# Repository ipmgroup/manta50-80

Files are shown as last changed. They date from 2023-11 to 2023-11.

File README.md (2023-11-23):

# manta50-80
Motor-Controller, FOC

### Manta50 key characteristics

    DC-Input 4.4V to 45V 
    Maximum DC / AC (per phase) current - 20A
    Texas Instruments C2000 Piccolo TMS320F28027F
    CAN - MCP2515
    Three-Phase Smart Gate Driver - DRV8305
    one GPIO input for PWM(not supported in FW)

with good cooling in water, you can increase the AC current to 80A. Replacing the resistance from 0.007R to 0.002R.

#### [Firmware](https://github.com/ipmgroup/manta50_fw)

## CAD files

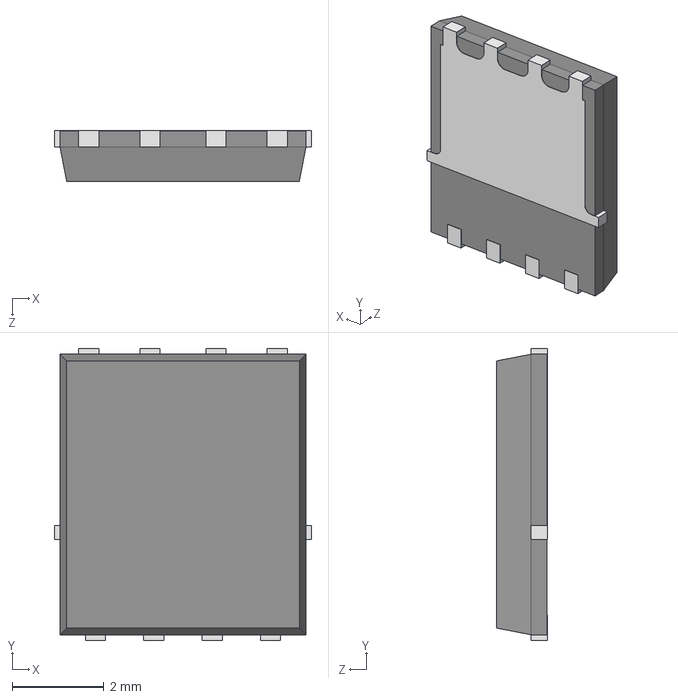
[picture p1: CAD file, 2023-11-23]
3D_MODELS/PG-TDSON-8_(INFIN).STEP
5.59 x 6.35 x 1.11 mm

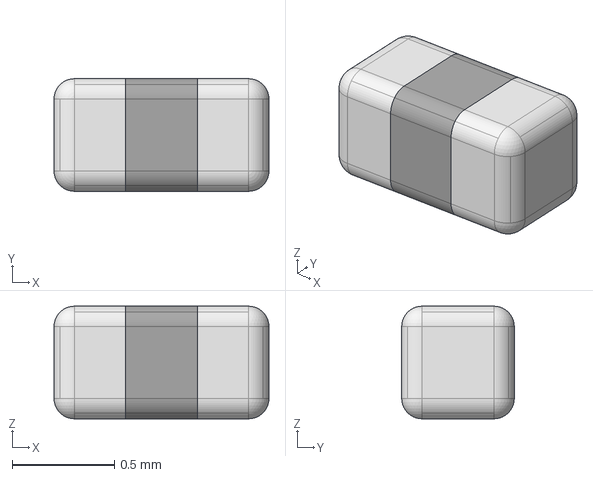
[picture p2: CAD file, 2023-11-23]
3D_MODELS/INDC1005X55N.stp
1.05 x 0.55 x 0.55 mm

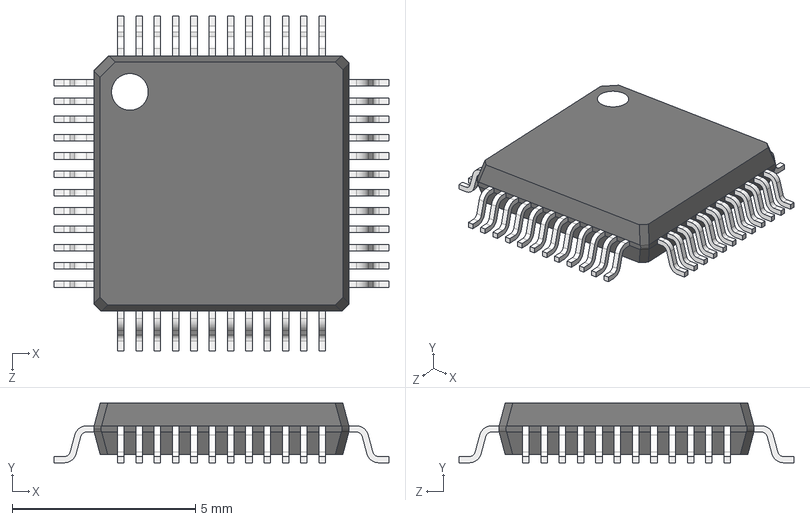
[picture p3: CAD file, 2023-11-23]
3D_MODELS/User Library-LQFP48-2.STEP
9.14 x 1.63 x 9.14 mm
User Library-LQFP48-2_case
User Library-LQFP48-2_pin x 48
User Library-LQFP48-2_circle

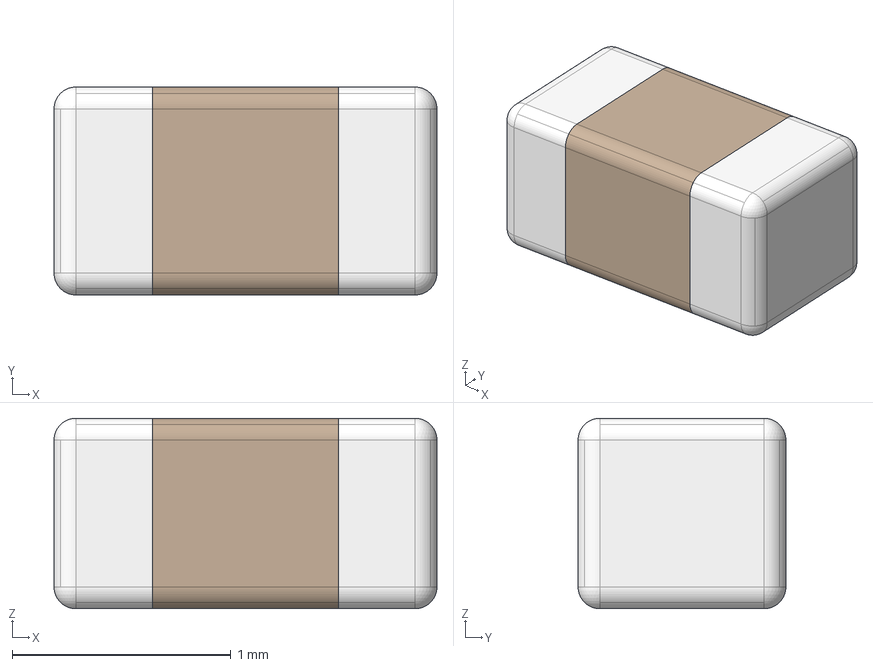
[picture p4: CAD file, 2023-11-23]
3D_MODELS/CAPC1608X87N.stp
1.75 x 0.95 x 0.87 mm

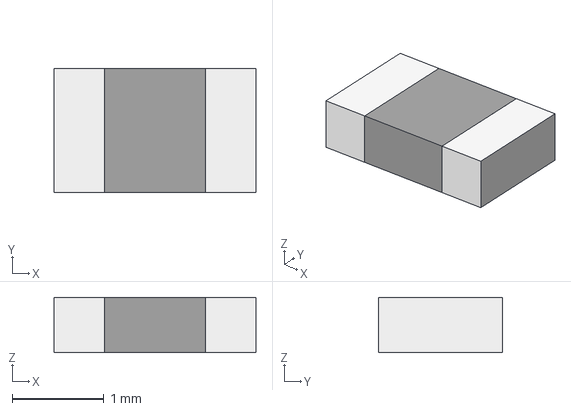
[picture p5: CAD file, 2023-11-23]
3D_MODELS/RESC2012X60N.stp
2.20 x 1.35 x 0.6 mm

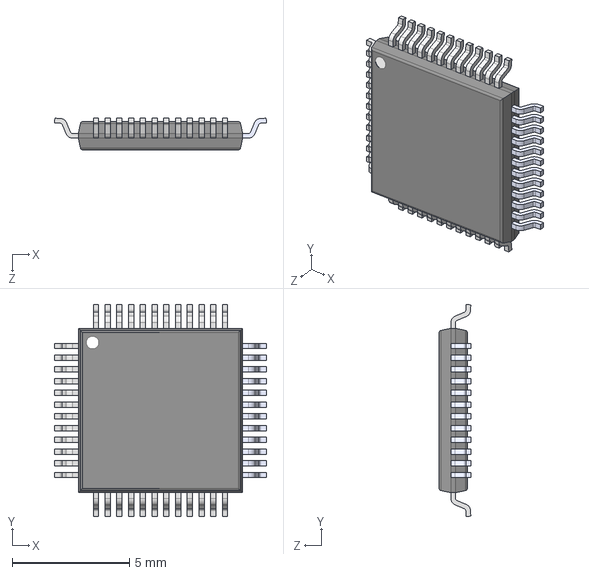
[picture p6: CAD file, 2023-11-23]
3D_MODELS/QFP50P900X900X120-49N.STEP
9.03 x 9.03 x 1.35 mm

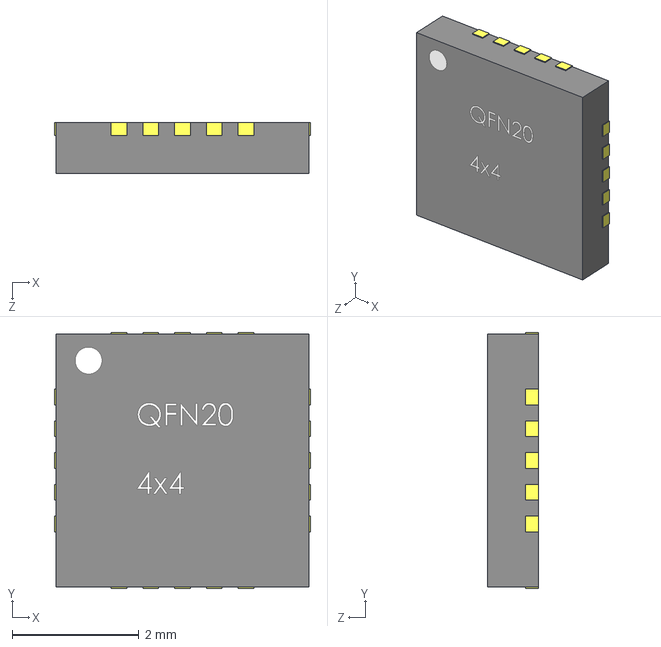
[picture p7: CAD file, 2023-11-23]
3D_MODELS/QFN4x4_20pins.STEP
4.04 x 4.04 x 0.802 mm

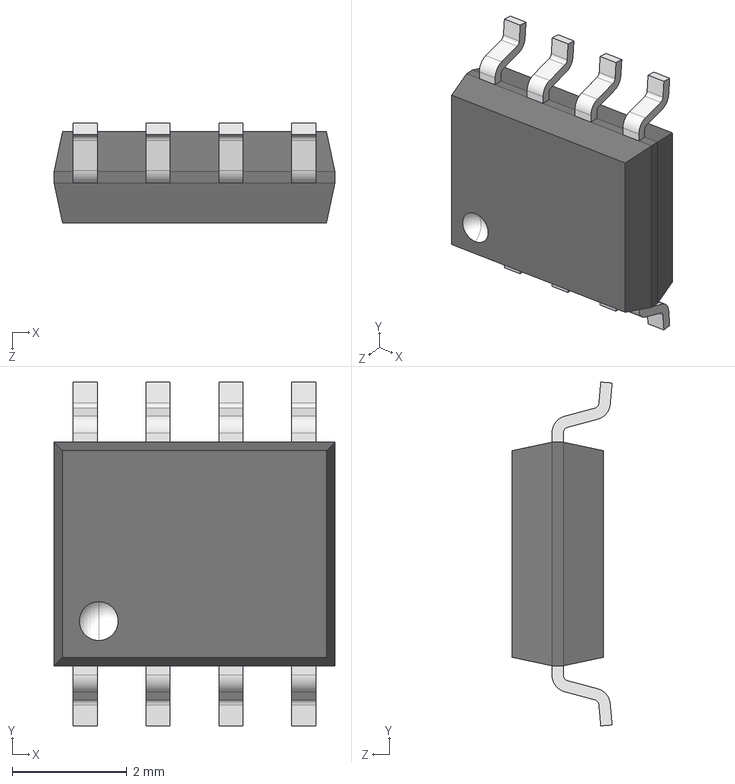
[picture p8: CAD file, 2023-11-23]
3D_MODELS/SOIC-8.STEP
4.90 x 6.00 x 1.75 mm

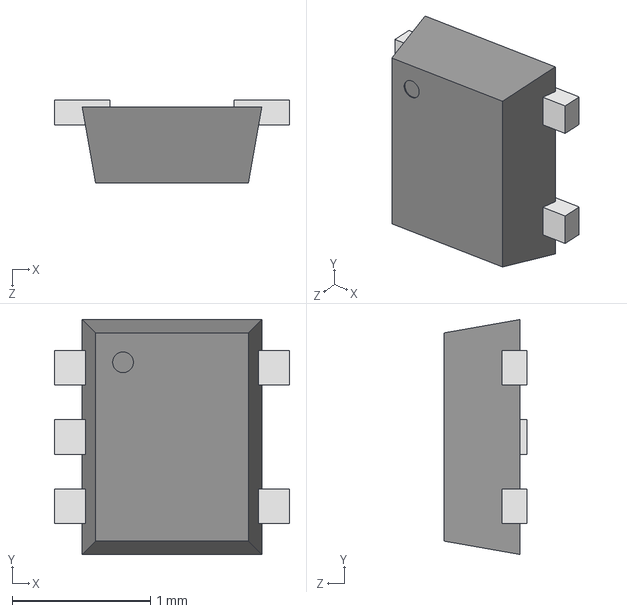
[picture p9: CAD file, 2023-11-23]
3D_MODELS/R-PDSO-N5.STEP
1.70 x 1.70 x 0.6 mm

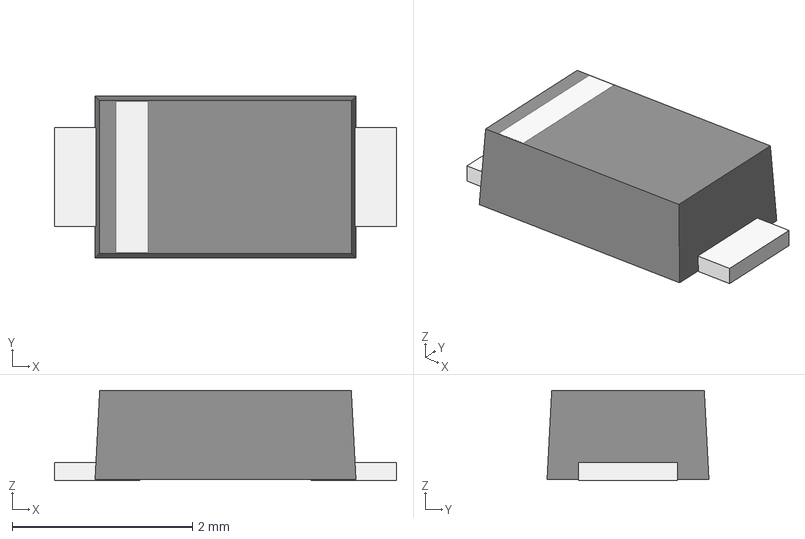
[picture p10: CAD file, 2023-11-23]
3D_MODELS/SOD-123FL.stp
3.80 x 1.80 x 1.00 mm

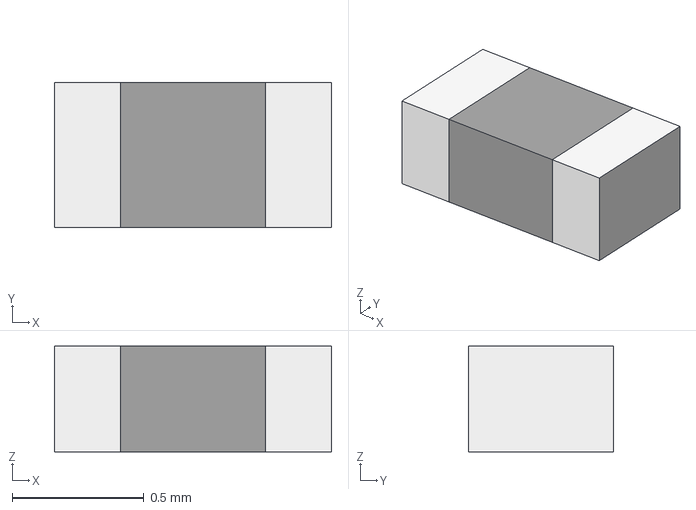
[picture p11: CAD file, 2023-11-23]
3D_MODELS/RESC1005X40N.stp
1.05 x 0.55 x 0.4 mm

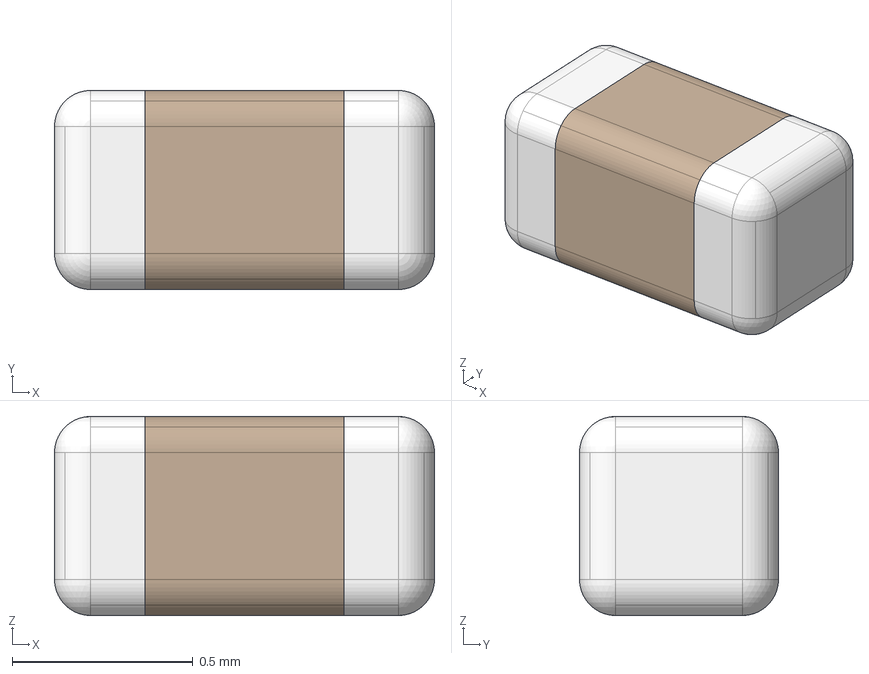
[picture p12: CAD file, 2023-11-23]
3D_MODELS/CAPC1005X55N.stp
1.05 x 0.55 x 0.55 mm

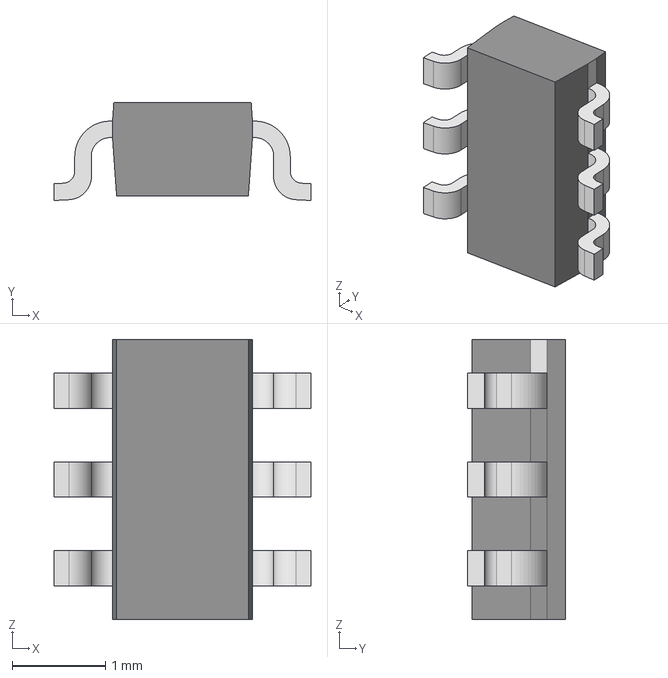
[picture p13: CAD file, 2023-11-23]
3D_MODELS/TSOP6.stp
2.75 x 1.05 x 3.00 mm

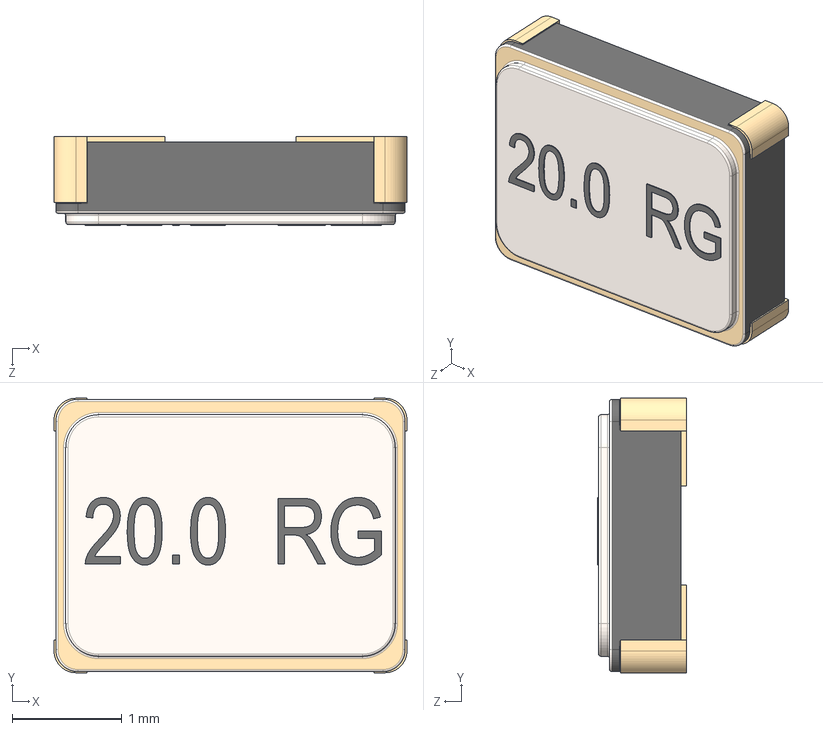
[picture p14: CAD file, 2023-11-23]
3D_MODELS/GeyerElectronics_KX7.STEP
3.21 x 2.50 x 0.81 mm

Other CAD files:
3D_MODELS/RESC1608X55N.stp
3D_MODELS/SOT23-6-2.STEP
3D_MODELS/Honeywell HIH-5031-1.STEP
3D_MODELS/98414-G06-06LF.STEP
3D_MODELS/SOT23.STEP

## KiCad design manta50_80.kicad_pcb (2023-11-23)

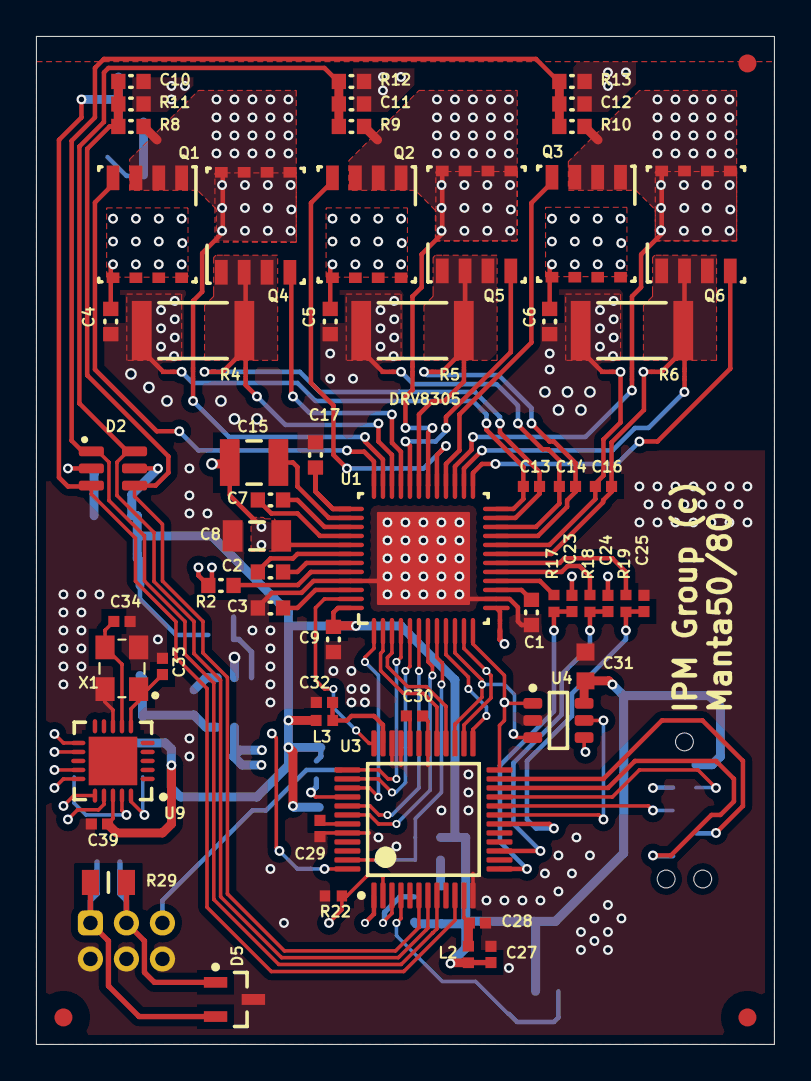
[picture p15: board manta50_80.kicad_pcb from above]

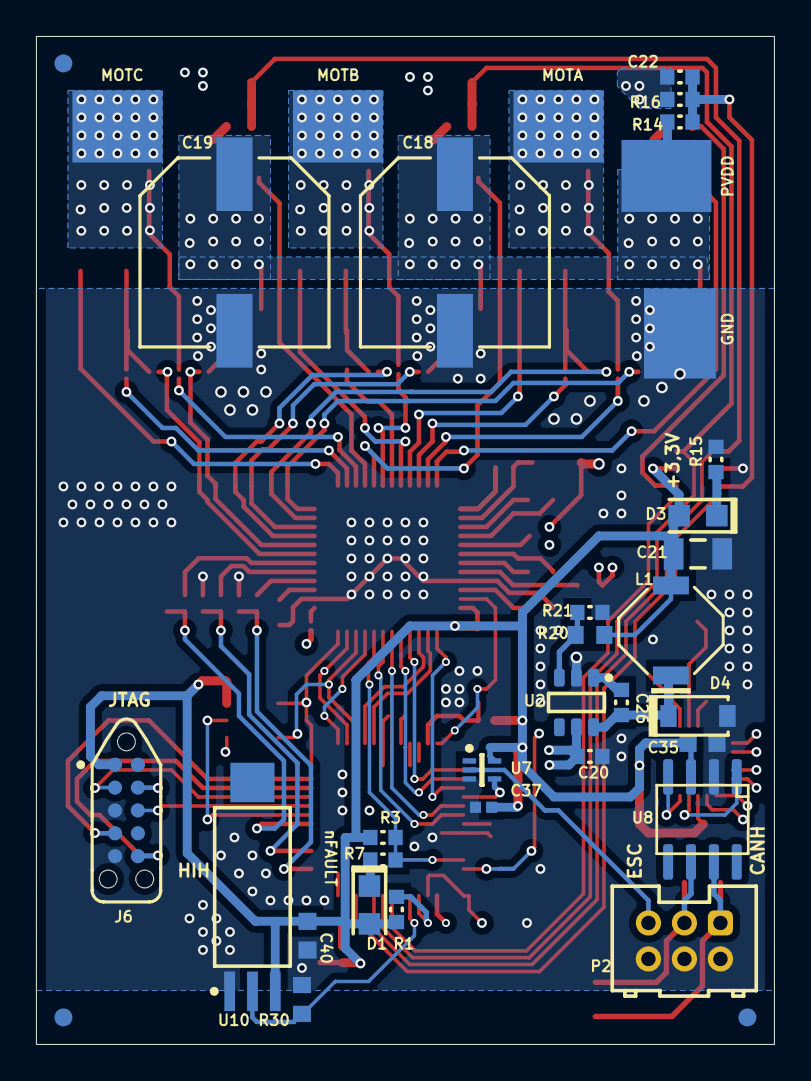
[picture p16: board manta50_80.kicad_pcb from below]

Board: 4 copper layers, 41.0 x 56.0 mm, 111 parts (36 on the bottom side), 87 nets.

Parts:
C1, C3, C4, C5, C6, C9, C17, C20: UMK107AB7105KA-T; 0603L
C2, C7: C0603C473K1RACTU; 0603L
C8: GRM31CR71H475KA12L; 1206L
C10, C11, C12, C22: C0603C104J4RACTU; 0603L
C13, C14, C16: 1nF; CAPC1005X55N
C15: GRM32ER72A225KA35L; 1210L
C18, C19: EEE-FT1H331AP; SM_RADIAL_G
C21: GRM31CR71A226KE15L; 1206L
C23, C24, C25: 2.2nF; CAPC1005X55N
C26: GRM188R71C334KA01D; 0603L
C27, C28, C29, C30, C32: 2.2uF; CAPC1005X55N
C31, C35, C40: 100nF; CAPC1608X87N
C33, C34: 22pF; CAPC1005X55N
C37, C39: 100nF; CAPC1005X55N
D1: LTST-C170KRKT; LED_LTST-C170
D2: NUP4201MR6T1G; TSOP-6
D3: LTST-C171GKT; LED_LTST-C171
D4: MBR1H100SFT3G; SOD-123FL
D5: SM712; SOT23_N
FID1, FID2, FID3, FID4, FID5, FID6: Fiducial; FIDUCIAL10-20
J1, J2, J3, J4, J5: 2 way net tie junction; J_PIN_4X5
J6: TC2050-IDC-NL-FP; TAG_TC2050-NL
L1: SD53-150-R; SD53
L2: 220R@100MHz; INDC1005X55N
L3: 60R@100MHz; INDC1005X55N
NT1, NT2, NT3, NT4, NT5, NT6, NT7, NT8, NT9, NT10, NT11, NT12, NT13: Net-Tie; NET-TIE_10MIL
P2: CAN; SHR6_V
Q1, Q2, Q3, Q4, Q5, Q6: CSD18540Q5B; TRANS_NEXFET_Q5B
R1, R3: CRCW060310K0JNEA; 0603L
R2: CRCW0603100RJNEA; 0603L
R4, R5, R6: CRE2512-FZ-R007E-3; 2512L
R7, R15: CRCW0603330RJNEA; 0603L
R8, R9, R10, R14: RC0603FR-0762KL; 0603L
R11, R12, R13, R16: RC0603FR-074K99L; 0603L
R17, R18, R19: 56; RESC1005X40N
R20, R30: 68k; RESC1608X55N
R21: CRCW060320K0FKEA; 0603L
R22: 2k2; RESC1005X40N
R29: 120; RESC2012X60N
U1: DRV8305NPHPQ1; PHP0048G_L
U2: LMR16006XDDC; SOT95P280X110-6N
U3: TMS320F28027F; TSQFP50P900X900X160-48N
U4: 25AA020; SOT95P270X145-6N
U7: SN74LVC1G34DRLR; SOTFL50P160X60-5N
U8: SN65HVD232; SOIC8-N_MC
U9: MCP2515-X/ML; QFN50P400X400X100_HS-21N
U10: HIH-5031; SOT127P1291X295-4N
X1: 16.000MHZ; CRYSTAL-3.2-2.5

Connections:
3.3V: C9.2, C21.1, C27.2, C31.2, C35.2, C37.2, C39.2, C40.2, D1.1, D2.5, D3.1, J6.1, L1.2, L2.2, L3.2, R1.2, R3.2, R20.2, U1.48, U4.6, U7.5, U8.3, U9.18, U10.3
AVDD: C1.2, U1.15
CANH: D5.2, P2.1, R29.1, U8.7
CANL: D5.1, P2.3, R29.2, U8.6
CAN_RX: U8.4, U9.20
CAN_TX: U8.1, U9.19
DVDD: C3.2, U1.46
ECAP1: U3.40, U7.4
EN_GATE: U1.1, U3.39
ESC: P2.5, U7.2
GH_A: Q1.4, U1.36
GH_B: Q2.4, U1.29
GH_C: Q3.4, U1.28
GL_A: Q4.4, U1.33
GL_B: Q5.4, U1.32
GL_C: Q6.4, U1.25
GND: C1.1, C3.1, C4.2, C5.2, C6.2, C8.1, C9.1, C10.2, C11.2, C12.2, C17.1, C18.2, C19.2, C20.2, C21.2, C22.2, C23.1, C24.1, C25.1, C27.1, C28.1, C29.1, C30.1, C31.1, C32.1, C33.1, C34.1, C35.1, C37.1, C39.1, C40.1, D2.2, D4.2, D5.3, J5.1, J6.3, J6.5, NT10.2, NT11.2, NT12.2, P2.2, P2.4, P2.6, R4.1, R5.1, R6.1, R11.1, R12.1, R13.1, R15.1, R16.1, R21.1, R22.1, R30.1, U1.14, U1.45, U1.49, U2.2, U3.12, U3.30, U3.33, U3.34, U3.44, U4.2, U7.3, U8.2, U9.8, U10.1, X1.2, X1.4
HIH: R30.2, U3.4, U10.2
INH_A: U1.2, U3.29
INH_B: U1.4, U3.37
INH_C: U1.6, U3.41
INL_A: U1.3, U3.28
INL_B: U1.5, U3.38
INL_C: U1.7, U3.42
ISEN_A: R17.2, U1.16
ISEN_B: R18.2, U1.17
ISEN_C: R19.2, U1.18
I_A: C23.2, R17.1, U3.13
I_B: C24.2, R18.1, U3.15
I_C: C25.2, R19.1, U3.18
MISO: U1.11, U3.26, U4.4, U9.15
MOSI: U1.10, U3.27, U4.3, U9.14
MOT_A: J1.1, NT1.2, Q1.1, Q1.2, Q1.3, Q4.5, Q4.6, Q4.7, Q4.8, R8.2
MOT_B: J2.1, NT2.2, Q2.1, Q2.2, Q2.3, Q5.5, Q5.6, Q5.7, Q5.8, R9.2
MOT_C: J3.1, NT3.2, Q3.1, Q3.2, Q3.3, Q6.5, Q6.6, Q6.7, Q6.8, R10.2
NCAN_CS: U3.1, U9.16
NCAN_INT: U3.48, U9.11
NFAULT: R3.1, R7.1, U1.8, U3.47
NRESET: NT13.1, R1.1, U3.3, U9.17
NetC2_1: C2.1, U1.43
NetC2_2: C2.2, U1.42
NetC7_1: C7.1, U1.39
NetC7_2: C7.2, U1.40
NetC15_2: C15.2, U1.38
NetC17_2: C17.2, U1.37
NetC26_1: C26.1, D4.1, L1.1, U2.6
NetC26_2: C26.2, U2.1
NetC28_2: C28.2, L2.1, U3.11
NetC29_2: C29.2, U3.43
NetC30_2: C30.2, U3.32
NetC32_2: C32.2, L3.1, U3.35
NetC33_2: C33.2, U9.6, X1.1
NetC34_2: C34.2, U9.7, X1.3
NetD1_2: D1.2, R7.2
NetD3_2: D3.2, R15.2
NetNT4_2: NT4.2, NT7.2, Q4.1, Q4.2, Q4.3, R4.2
NetNT5_2: NT5.2, NT8.2, Q5.1, Q5.2, Q5.3, R5.2
NetNT6_2: NT6.2, NT9.2, Q6.1, Q6.2, Q6.3, R6.2
NetR2_1: R2.1, U1.44
NetR20_1: R20.1, R21.2, U2.3
PVDD: C4.1, C5.1, C6.1, C8.2, C15.1, C18.1, C19.1, C20.1, J4.1, Q1.5, Q1.6, Q1.7, Q1.8, Q2.5, Q2.6, Q2.7, Q2.8, Q3.5, Q3.6, Q3.7, Q3.8, R2.2, R14.2, U1.41, U2.5
PWRGD: NT13.2, U1.13
S1_N: C13.2, NT7.1, U1.23
S1_P: C13.1, NT10.1, U1.24
S2_N: C14.2, NT8.1, U1.21
S2_P: C14.1, NT11.1, U1.22
S3_N: C16.2, NT9.1, U1.19
S3_P: C16.1, NT12.1, U1.20
SCK: U1.12, U3.24, U4.1, U9.12
SCS: U1.9, U3.25
SCS2: U3.19, U4.5
SH_A: NT1.1, U1.35
SH_B: NT2.1, U1.30
SH_C: NT3.1, U1.27
SL_A: NT4.1, U1.34
SL_B: NT5.1, U1.31
SL_C: NT6.1, U1.26
TCK: J6.4, U3.23
TDI: J6.8, U3.20
TDO: J6.6, U3.22
TMS: J6.2, U3.21
TRSTN: J6.9, R22.2, U3.2
VSEN_A: C10.1, D2.4, R8.1, R11.2, U3.6
VSEN_B: C11.1, D2.6, R9.1, R12.2, U3.7
VSEN_C: C12.1, D2.1, R10.1, R13.2, U3.8
VSEN_PVDD: C22.1, D2.3, R14.1, R16.2, U3.10
WAKE: U1.47, U3.36
